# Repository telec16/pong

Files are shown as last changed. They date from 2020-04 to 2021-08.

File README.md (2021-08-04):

# Analog pong

The pong game, all in analog and on your scope !

# Design explanation

TODO... The KiCAD files are well documented though.

# Build

## Score counter

I decided to build the score counter in free-form, since it has all these diodes, it would be huge on a regular PCB.

Score board top The top view seems ok...

Score board side Look at all these diodes!

Score board bottom The bottom is a little hacky, but good enough

Score board DAC Adding the DAC

Score board ramp The two produced stairs ramps
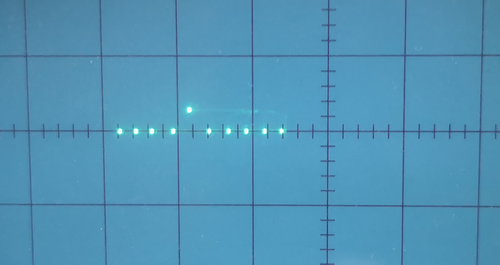
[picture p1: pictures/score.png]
Score board result It's working well!


## Goal detector

The goal detector PCB is a tilable design: you need two PCBs to make one. It lowers PCB cost (divide by two) and uses a little less components.

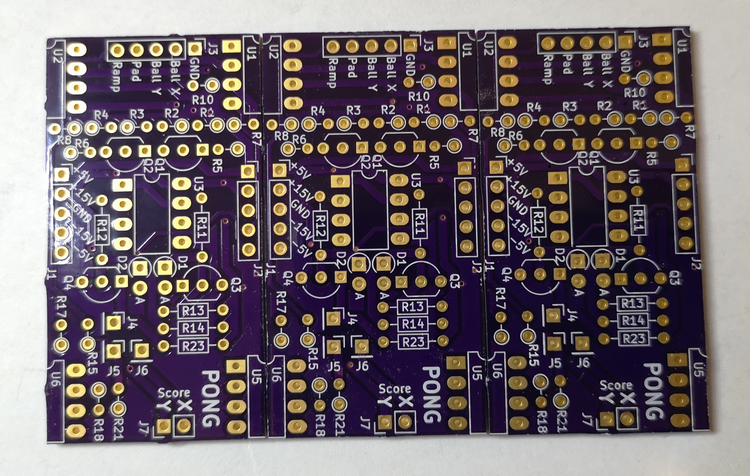
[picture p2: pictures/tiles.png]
Tiles Three PCB aligned, to make a bigger one


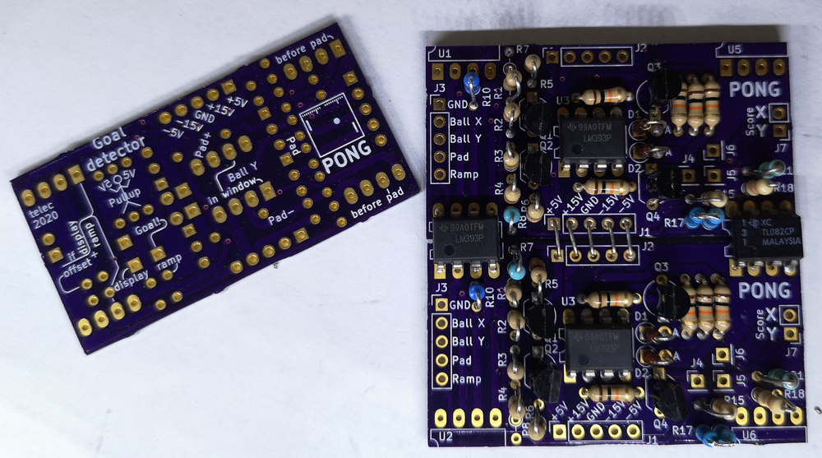
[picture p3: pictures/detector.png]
Goal detector board With all the components mounted and soldered, it works like a charm!


More pictures to come, I guess.

## Oscillator

I have hand-drawn the oscillator board, and etched it at home. It looks nice, I think.

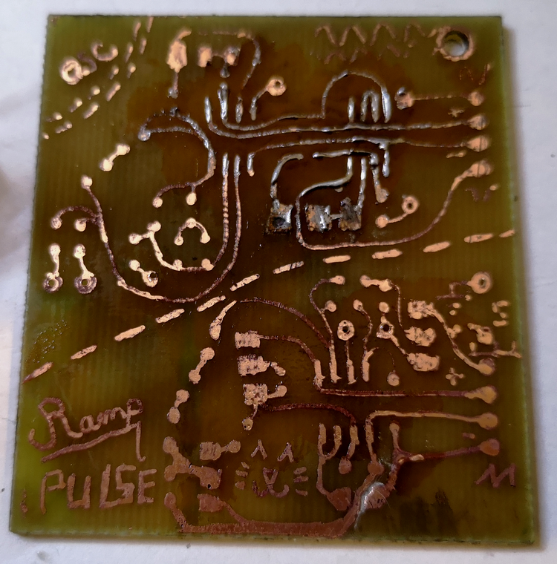
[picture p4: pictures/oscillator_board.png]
Oscillator board It's a little too much etched.


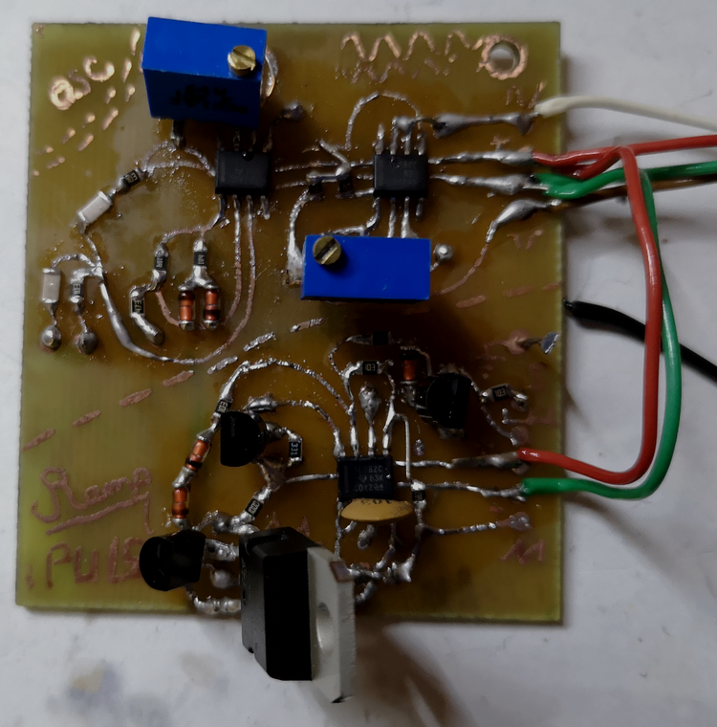
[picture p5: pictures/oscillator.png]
Oscillator board I remplaced the 2N2222 with a TIP120


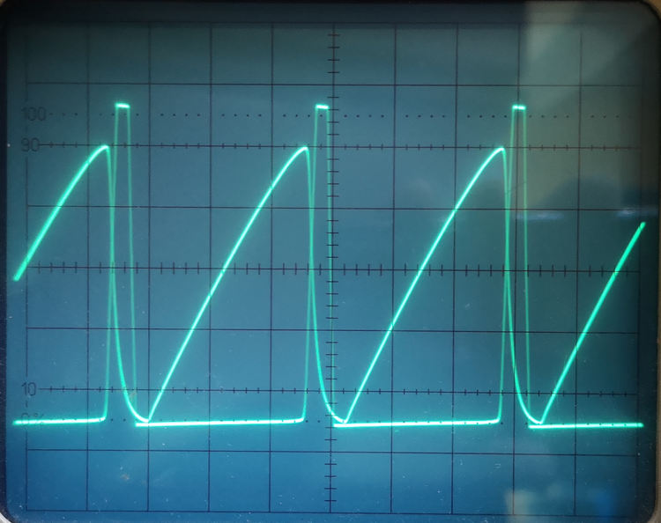
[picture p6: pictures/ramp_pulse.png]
Ramp and Pulse It works well!


The ball oscillator+phaser works well (pictures in coming). But the ramp/pulse oscillator have to put 1W in a transistor, oops... Bad design, I need to change that...

# License

This work is licensed under a [Creative Commons Attribution-ShareAlike 4.0
International License][cc-by-sa].

[][cc-by-sa]

[cc-by-sa]: http://creativecommons.org/licenses/by-sa/4.0/
[cc-by-sa-image]: https://licensebuttons.net/l/by-sa/4.0/88x31.png
[cc-by-sa-shield]: https://img.shields.io/badge/License-CC%20BY--SA%204.0-lightgrey.svg

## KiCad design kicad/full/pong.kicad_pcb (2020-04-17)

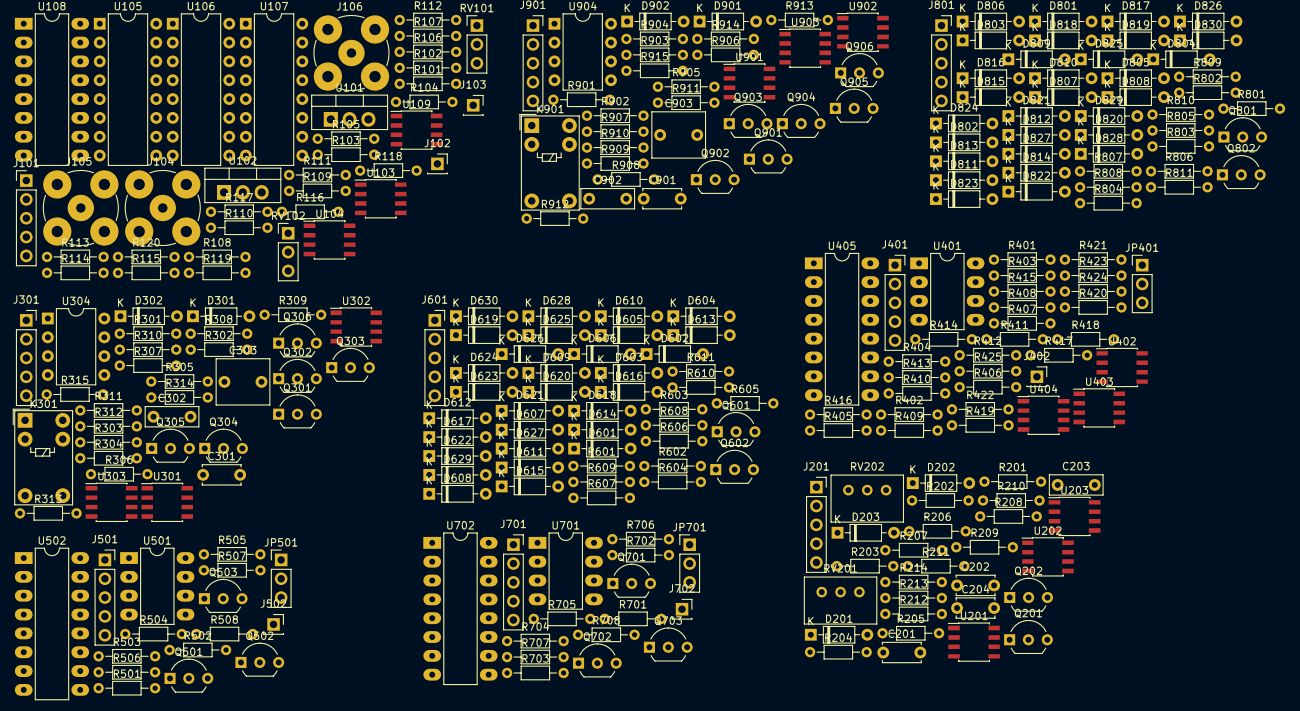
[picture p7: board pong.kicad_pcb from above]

Board: 2 copper layers, 283 parts (0 on the bottom side), 181 nets, no tracks yet.

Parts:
C201, C202, C204: 1n; C_Disc_D5.0mm_W2.5mm_P5.00mm
C203, C302, C902: 100n; C_Rect_L7.0mm_W2.5mm_P5.00mm
C301, C901: 47n; C_Disc_D5.0mm_W2.5mm_P5.00mm
C303, C903: C; C_Rect_L7.0mm_W6.0mm_P5.00mm
D201, D202, D203, D301, D302, D601, D602, D603, D604, D605, D606, D607, D608, D609, D610, D611, D612, D613, D614, D615, D616, D617, D618, D619, D620, D621, D622, D623, D624, D625, D626, D627, D628, D629, D630, D801, D802, D803, D804, D805, D806, D807, D808, D809, D810, D811, D812, D813, D814, D815, D816, D817, D818, D819, D820, D821, D822, D823, D824, D825, D826, D827, D828, D829, D830, D901, D902: 1N4148; D_DO-35_SOD27_P7.62mm_Horizontal
J101: power; PinHeader_1x05_P2.54mm_Vertical
J102: Y_F; PinSocket_1x01_P2.54mm_Vertical
J103: X_F; PinSocket_1x01_P2.54mm_Vertical
J104: X; BNC_TEConnectivity_1478204_Vertical
J105: Y; BNC_TEConnectivity_1478204_Vertical
J106: Z; BNC_TEConnectivity_1478204_Vertical
J201, J301, J401, J501, J601, J701, J801, J901: power; PinSocket_1x05_P2.54mm_Vertical
J402, J502, J702: Reset; PinSocket_1x01_P2.54mm_Vertical
JP401, JP501, JP701: Max_Point; PinHeader_1x03_P2.54mm_Vertical
K301, K901: G5V-1; Relay_SPDT_Omron_G5V-1
Q201, Q303, Q903: BC557; TO-92_Inline_Wide
Q202, Q304, Q306, Q904, Q906: 2N3819; TO-92_Inline_Wide
Q301, Q302, Q305, Q501, Q502, Q503, Q601, Q602, Q701, Q702, Q703, Q801, Q802, Q901, Q902, Q905: BC547; TO-92_Inline_Wide
R101, R102, R103, R104, R105, R106, R107, R108, R213, R310, R311, R312, R401, R402, R403, R404, R407, R408, R411, R412, R413, R414, R910, R911, R912: R; R_Axial_DIN0204_L3.6mm_D1.6mm_P7.62mm_Horizontal
R109, R112, R409, R410, R507, R707: 1k; R_Axial_DIN0204_L3.6mm_D1.6mm_P7.62mm_Horizontal
R110, R111, R405, R406: 100; R_Axial_DIN0204_L3.6mm_D1.6mm_P7.62mm_Horizontal
R113, R114, R115, R116, R117, R118, R119, R120, R205, R305, R306, R307, R905, R906, R907: 100k; R_Axial_DIN0204_L3.6mm_D1.6mm_P7.62mm_Horizontal
R201, R202, R206, R208, R210, R211, R212, R301, R302, R303, R304, R308, R309, R313, R314, R315, R416, R417, R502, R504, R505, R506, R508, R601, R602, R603, R604, R605, R606, R607, R608, R609, R610, R611, R702, R704, R705, R706, R708, R801, R802, R803, R804, R805, R806, R807, R808, R809, R810, R811, R901, R902, R903, R904, R908, R909, R913, R914, R915: 10k; R_Axial_DIN0204_L3.6mm_D1.6mm_P7.62mm_Horizontal
R203, R415: 47k; R_Axial_DIN0204_L3.6mm_D1.6mm_P7.62mm_Horizontal
R204, R207: 180k; R_Axial_DIN0204_L3.6mm_D1.6mm_P7.62mm_Horizontal
R209, R214, R501, R503, R701, R703: 4k7; R_Axial_DIN0204_L3.6mm_D1.6mm_P7.62mm_Horizontal
R418, R419, R421, R423: 33k; R_Axial_DIN0204_L3.6mm_D1.6mm_P7.62mm_Horizontal
R420, R422: 75k; R_Axial_DIN0204_L3.6mm_D1.6mm_P7.62mm_Horizontal
R424, R425: 68k; R_Axial_DIN0204_L3.6mm_D1.6mm_P7.62mm_Horizontal
RV101, RV102: R_POT; PinHeader_1x03_P2.54mm_Vertical
RV201, RV202: 10k; Potentiometer_Bourns_3299W_Vertical
U101: L7805; TO-220-3_Vertical
U102: L7905; TO-220-3_Vertical
U103, U104, U109, U201, U202, U203, U301, U302, U303, U402, U403, U404, U901, U902, U903: TL082; SOIC-8_3.9x4.9mm_P1.27mm
U105, U106, U107: DG445; DIP-16_W7.62mm
U108, U405, U502, U702: 4017; DIP-16_W7.62mm_LongPads
U304, U904: DG470; DIP-8_W7.62mm
U401, U501, U701: LM393; DIP-8_W7.62mm_LongPads

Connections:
+5V: J101.1, J201.1, J301.1, J401.1, J501.1, J601.1, J701.1, J801.1, J901.1, K301.2, K901.2, R103.1, R107.1, R111.1, R308.1, R405.2, R507.1, R508.1, R601.2, R602.2, R603.2, R604.2, R605.2, R606.2, R607.2, R608.2, R609.2, R610.2, R611.1, R707.1, R708.1, R801.2, R802.2, R803.2, R804.2, R805.2, R806.2, R807.2, R808.2, R809.2, R810.2, R811.1, R908.1, U101.3, U105.12, U106.12, U107.12, U108.16, U405.16, U502.16, U702.16
+15V: J101.2, J201.2, J301.2, J401.2, J501.2, J601.2, J701.2, J801.2, J901.2, Q202.1, Q303.3, Q903.3, R303.1, R505.1, R705.1, R903.1, U101.1, U103.4, U104.4, U105.13, U106.13, U107.13, U109.4, U201.8, U202.8, U203.8, U301.8, U302.8, U303.8, U304.4, U401.4, U402.8, U403.8, U404.8, U501.8, U701.8, U901.8, U902.8, U903.8, U904.4
-5V: J101.5, J201.5, J301.5, J401.5, J501.5, J601.5, J701.5, J801.5, J901.5, R104.2, R108.2, R110.1, R406.2, R420.2, R422.2, U102.3
-15V: C203.1, J101.4, J201.4, J301.4, J401.4, J501.4, J601.4, J701.4, J801.4, J901.4, Q201.1, R506.2, R706.2, U102.2, U103.8, U104.8, U105.4, U106.4, U107.4, U109.8, U201.4, U202.4, U203.4, U301.4, U302.4, U303.4, U304.7, U401.8, U402.4, U403.4, U404.4, U501.4, U701.4, U901.4, U902.4, U903.4, U904.7
/A: U105.1, U105.8, U108.3
/B: U106.1, U107.1, U108.2
/Ball/Bounce: R309.1, R311.1, U302.1
/Ball_X: R315.1, U105.6, U303.1
/Ball_Y: R915.1, U105.2, U903.1
/C: U106.8, U107.8, U108.4
/Cos: R913.2, RV202.1, RV202.2, U202.7
/D: U106.9, U107.9, U108.7
/Disp_Pad_1: R119.1, U106.2, U109.1
/Disp_Pad_2: R120.1, U106.6, U109.7
/E: U106.16, U107.16, U108.10
/F: U105.9, U105.16, U108.1
/New_Frame: U108.5, U108.15, U405.14
/Pad_1: R114.2, U104.1, U402.3
/Pad_2: R117.2, U104.7, U402.5
/Pos_X: C303.2, Q306.1, R312.2, R314.2, U302.7, U401.3, U401.6
/Pos_Y: C903.2, Q906.1, R912.2, R914.2, U501.3, U501.6, U701.3, U701.6, U902.7
/Pulse: J106.1, R202.1, R212.2, U108.14, U203.7
/Rampe: D201.1, R101.1, R105.1, R210.1, U203.1, U203.2
/Rampe_pad: R115.2, R118.2, U103.1
/Rampe_point: R418.2, R419.2, U103.7
/Reset: R302.1, R902.1
/Score/Q0: D602.1, D802.1, R401.1, U405.3
/Score/Q1: D604.1, D804.1, R402.1, U405.2
/Score/Q2: D606.1, D806.1, R403.1, U405.4
/Score/Q3: D608.1, D808.1, R404.1, U405.7
/Score/Q4: D610.1, D810.1, R407.1, U405.10
/Score/Q5: D612.1, D812.1, R408.1, U405.1
/Score/Q6: D614.1, D814.1, R411.1, U405.5
/Score/Q7: D616.1, D816.1, R412.1, U405.6
/Score/Q8: D618.1, D818.1, R413.1, U405.9
/Score/Q9: D620.1, D820.1, R414.1, U405.11
/Score/sheet5C9A25F6/Edge: Q503.1, R508.2, U401.7, U502.14
/Score/sheet5C9A25F6/Pad: Q501.3, Q502.1, R502.2, R503.1, U402.6, U402.7
/Score/sheet5C9A25F6/Pad+: Q501.1, R501.1, R505.2, U501.2
/Score/sheet5C9A25F6/Pad-: Q502.3, R504.2, R506.1, U501.5
/Score/sheet5C9A25F6/Score_Display: Q602.1, R419.1, R423.2
/Score/sheet5C9A25F6/sheet5C868ABE/A1: D601.1, U502.3
/Score/sheet5C9A25F6/sheet5C868ABE/B1: D603.1, U502.2
/Score/sheet5C9A25F6/sheet5C868ABE/C1: D605.1, U502.4
/Score/sheet5C9A25F6/sheet5C868ABE/D1: D607.1, U502.7
/Score/sheet5C9A25F6/sheet5C868ABE/E1: D609.1, U502.10
/Score/sheet5C9A25F6/sheet5C868ABE/F1: D611.1, U502.1
/Score/sheet5C9A25F6/sheet5C868ABE/G1: D613.1, U502.5
/Score/sheet5C9A25F6/sheet5C868ABE/H1: D615.1, U502.6
/Score/sheet5C9A25F6/sheet5C868ABE/I1: D617.1, U502.9
/Score/sheet5C9A25F6/sheet5C868ABE/J1: D619.1, U502.11
/Score/sheet5CC39077/Edge: Q703.1, R708.2, U401.1, U702.14
/Score/sheet5CC39077/Pad: Q701.3, Q702.1, R702.2, R703.1, U402.1, U402.2
/Score/sheet5CC39077/Pad+: Q701.1, R701.1, R705.2, U701.2
/Score/sheet5CC39077/Pad-: Q702.3, R704.2, R706.1, U701.5
/Score/sheet5CC39077/Score_Display: Q802.1, R418.1, R421.2
/Score/sheet5CC39077/sheet5C868ABE/A1: D801.1, U702.3
/Score/sheet5CC39077/sheet5C868ABE/B1: D803.1, U702.2
/Score/sheet5CC39077/sheet5C868ABE/C1: D805.1, U702.4
/Score/sheet5CC39077/sheet5C868ABE/D1: D807.1, U702.7
/Score/sheet5CC39077/sheet5C868ABE/E1: D809.1, U702.10
/Score/sheet5CC39077/sheet5C868ABE/F1: D811.1, U702.1
/Score/sheet5CC39077/sheet5C868ABE/G1: D813.1, U702.5
/Score/sheet5CC39077/sheet5C868ABE/H1: D815.1, U702.6
/Score/sheet5CC39077/sheet5C868ABE/I1: D817.1, U702.9
/Score/sheet5CC39077/sheet5C868ABE/J1: D819.1, U702.11
/Score_1: C301.2, Q306.2
/Score_2: C901.2, Q906.2
/Score_Display_1: R424.1, U106.10, U404.1
/Score_Display_2: R425.1, U106.15, U404.7
/Score_X: R415.1, R416.2, U107.10, U403.1
/Sin: R211.2, R313.2, RV201.1, RV201.2, U202.1
/X_out: J104.1, U105.7, U105.11, U107.3, U107.7, U107.11, U107.14
/Y_out: J105.1, U105.3, U105.14, U106.3, U106.7, U106.11, U106.14
/sheet5C7A25B3/Bounce: R909.1, R911.1, U902.1
/~Score_X: R417.1, U107.15, U403.7
GND: C201.1, C204.1, C302.1, C902.1, D301.2, D302.2, D901.2, D902.2, J101.3, J104.2, J105.2, J106.2, J201.3, J301.3, J401.3, J501.3, J601.3, J701.3, J801.3, J901.3, JP401.1, JP501.1, JP701.1, Q301.3, Q302.3, Q305.3, Q503.3, Q601.3, Q602.3, Q703.3, Q801.3, Q802.3, Q901.3, Q902.3, Q905.3, R102.2, R106.2, R109.2, R112.2, R113.2, R116.2, R201.1, R203.1, R208.1, R213.1, R301.2, R409.2, R410.2, R901.2, U101.2, U102.1, U103.3, U103.5, U104.3, U104.5, U105.5, U106.5, U107.5, U108.8, U108.13, U203.6, U301.5, U302.2, U302.5, U303.3, U304.3, U304.5, U403.3, U403.5, U404.3, U404.5, U405.8, U405.13, U502.8, U502.13, U702.8, U702.13, U901.5, U902.2, U902.5, U903.3, U904.3, U904.5
unnamed: C201.2, C202.2, R201.2, U201.3
unnamed: C202.1, R206.2
unnamed: C203.2, Q201.3, Q202.2, R205.2, U203.3
unnamed: C204.2, R211.1, U202.5
unnamed: C301.1, D301.1, Q301.2, R301.1
unnamed: C302.2, Q302.1, Q304.2, R305.2, U301.3
unnamed: C303.1, Q306.3, R310.1, U302.6
unnamed: C901.1, D901.1, Q901.2, R901.1
unnamed: C902.2, Q902.1, Q904.2, R905.2, U901.3
unnamed: C903.1, Q906.3, R910.1, U902.6
unnamed: D201.2, Q201.2, R202.2
unnamed: D202.1, D203.2, R206.1, R207.1, U201.1, U202.3
unnamed: D202.2, D203.1, R204.1
unnamed: D302.1, Q305.2, R309.2
unnamed: D601.2, D602.2, D621.2, R601.1
unnamed: D603.2, D604.2, D622.2, R602.1
unnamed: D605.2, D606.2, D623.2, R603.1
unnamed: D607.2, D608.2, D624.2, R604.1
unnamed: D609.2, D610.2, D625.2, R605.1
unnamed: D611.2, D612.2, D626.2, R606.1
unnamed: D613.2, D614.2, D627.2, R607.1
unnamed: D615.2, D616.2, D628.2, R608.1
unnamed: D617.2, D618.2, D629.2, R609.1
unnamed: D619.2, D620.2, D630.2, R610.1
unnamed: D621.1, D622.1, D623.1, D624.1, D625.1, D626.1, D627.1, D628.1, D629.1, D630.1, Q601.2
unnamed: D801.2, D802.2, D821.2, R801.1
unnamed: D803.2, D804.2, D822.2, R802.1
unnamed: D805.2, D806.2, D823.2, R803.1
unnamed: D807.2, D808.2, D824.2, R804.1
unnamed: D809.2, D810.2, D825.2, R805.1
unnamed: D811.2, D812.2, D826.2, R806.1
unnamed: D813.2, D814.2, D827.2, R807.1
unnamed: D815.2, D816.2, D828.2, R808.1
unnamed: D817.2, D818.2, D829.2, R809.1
unnamed: D819.2, D820.2, D830.2, R810.1
unnamed: D821.1, D822.1, D823.1, D824.1, D825.1, D826.1, D827.1, D828.1, D829.1, D830.1, Q801.2
unnamed: D902.1, Q905.2, R909.2
unnamed: J102.1, U105.15
unnamed: J103.1, U105.10
unnamed: J402.1, JP401.3
unnamed: J502.1, JP501.3
unnamed: J702.1, JP701.3
unnamed: JP401.2, U405.15
unnamed: JP501.2, U502.15
unnamed: JP701.2, U702.15
unnamed: K301.1, R307.1, U301.7, U304.8
unnamed: K301.5, K301.6, R310.2, U304.1
unnamed: K301.9, Q305.1, R308.2, U304.6
unnamed: K301.10, R306.1, U301.1, U301.2, U304.2
unnamed: K901.1, R907.1, U901.7, U904.8
unnamed: K901.5, K901.6, R910.2, U904.1
unnamed: K901.9, Q905.1, R908.2, U904.6
unnamed: K901.10, R906.1, U901.1, U901.2, U904.2
unnamed: Q202.3, R205.1
unnamed: Q301.1, R304.2
unnamed: Q302.2, R302.2
unnamed: Q303.1, Q304.1
unnamed: Q303.2, R303.2, R304.1
unnamed: Q304.3, R305.1
unnamed: Q501.2, R501.2, R502.1
unnamed: Q502.2, R503.2, R504.1
unnamed: Q503.2, R507.2, U501.1, U501.7
unnamed: Q601.1, Q602.2, R611.2
unnamed: Q701.2, R701.2, R702.1
unnamed: Q702.2, R703.2, R704.1
unnamed: Q703.2, R707.2, U701.1, U701.7
unnamed: Q801.1, Q802.2, R811.2
unnamed: Q901.1, R904.2
unnamed: Q902.2, R902.2
unnamed: Q903.1, Q904.1
unnamed: Q903.2, R903.2, R904.1
unnamed: Q904.3, R905.1
unnamed: R101.2, R102.1, U103.2
unnamed: R103.2, RV101.1
unnamed: R104.1, RV101.3
unnamed: R105.2, R106.1, U103.6
unnamed: R107.2, RV102.1
unnamed: R108.1, RV102.3
unnamed: R109.1, R110.2, U107.6
unnamed: R111.2, R112.1, U107.2
unnamed: R113.1, R119.2, U109.2
unnamed: R114.1, R115.1, U109.3
unnamed: R116.1, R120.2, U109.6
unnamed: R117.1, R118.1, U109.5
unnamed: R203.2, R204.2, R207.2, U201.2
unnamed: R208.2, R209.2, U202.2
unnamed: R209.1, RV201.3
unnamed: R210.2, R212.1, U203.5
unnamed: R213.2, R214.2, U202.6
unnamed: R214.1, RV202.3
unnamed: R306.2, R307.2, U301.6
unnamed: R311.2, R312.1, U302.3
unnamed: R313.1, R314.1, R315.2, U303.2
unnamed: R401.2, R402.2, R403.2, R404.2, R407.2, R408.2, R411.2, R412.2, R413.2, R414.2, R415.2, U403.2
unnamed: R405.1, R409.1, U401.2
unnamed: R406.1, R410.1, U401.5
unnamed: R416.1, R417.2, U403.6
unnamed: R420.1, R421.1, R424.2, U404.2
unnamed: R422.1, R423.1, R425.2, U404.6
unnamed: R906.2, R907.2, U901.6
unnamed: R911.2, R912.1, U902.3
unnamed: R913.1, R914.1, R915.2, U903.2
unnamed: RV101.2, U104.2
unnamed: RV102.2, U104.6

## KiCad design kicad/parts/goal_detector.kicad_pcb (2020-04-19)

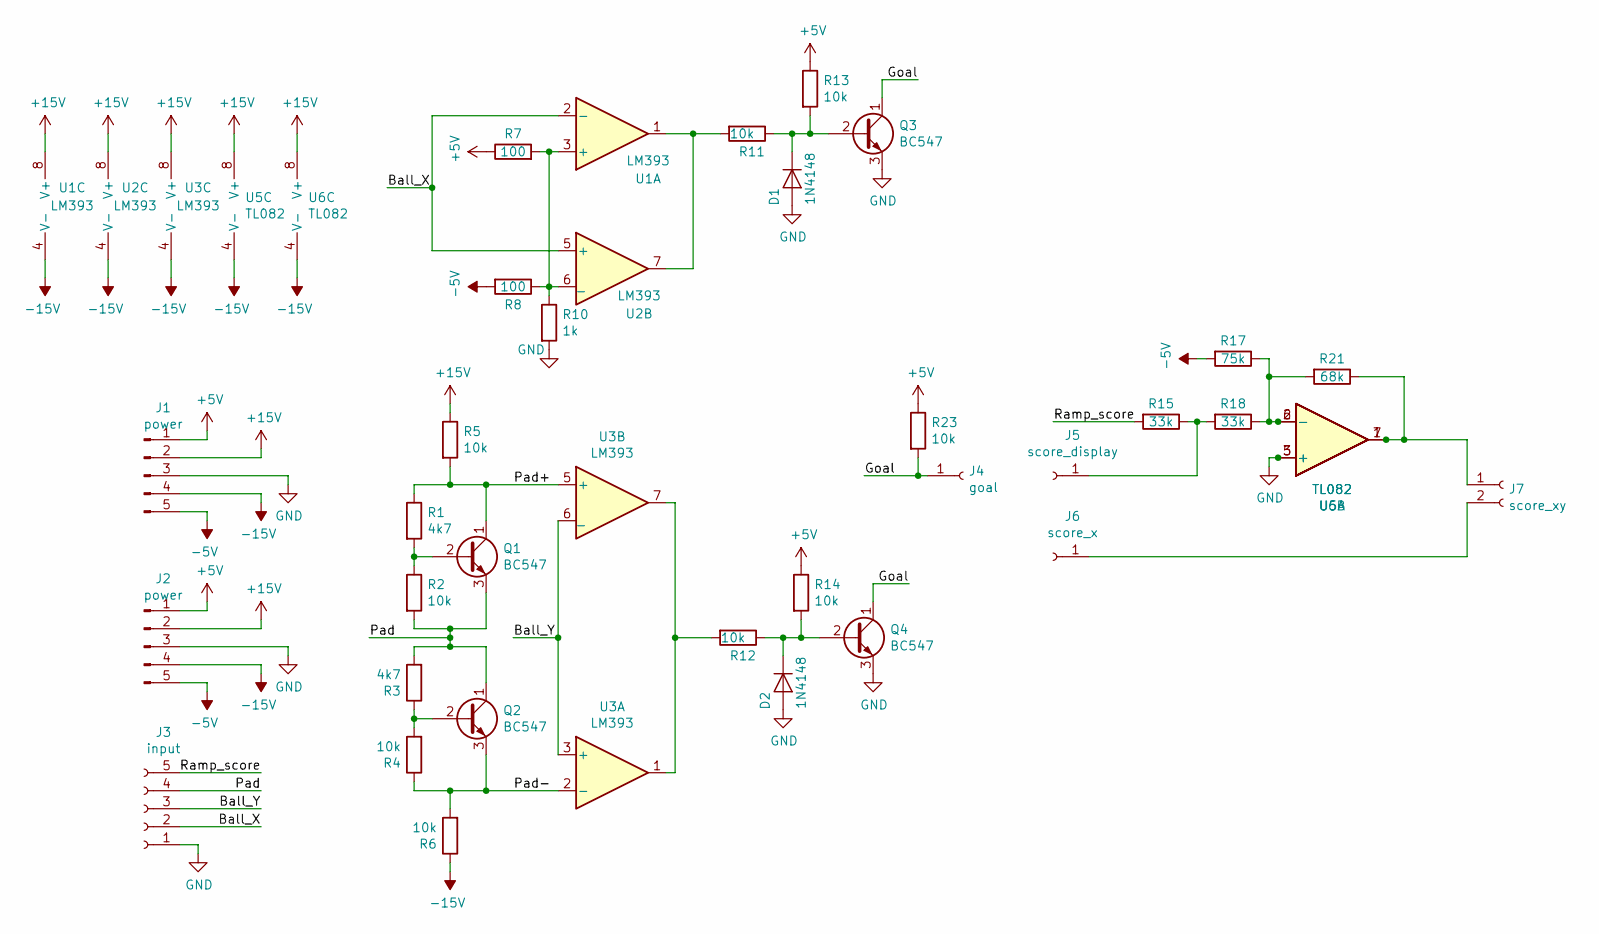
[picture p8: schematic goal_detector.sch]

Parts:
D1, D2: 1N4148; D_A-405_P2.54mm_Vertical_AnodeUp
J1, J2: power; PinSocket_1x05_P2.54mm_Vertical
J3: input; PinHeader_1x05_P2.54mm_Vertical
J4: goal; PinHeader_1x01_P2.54mm_Vertical
J5: score_display; PinHeader_1x01_P2.54mm_Vertical
J6: score_x; PinHeader_1x01_P2.54mm_Vertical
J7: score_xy; PinHeader_1x02_P2.54mm_Vertical
Q1, Q2, Q3, Q4: BC547; TO-92_Inline_Wide
R1, R3: 4k7; R_Axial_DIN0204_L3.6mm_D1.6mm_P2.54mm_Vertical
R2, R4, R5, R6: 10k; R_Axial_DIN0204_L3.6mm_D1.6mm_P2.54mm_Vertical
R7, R8: 100; R_Axial_DIN0204_L3.6mm_D1.6mm_P2.54mm_Vertical
R10: 1k; R_Axial_DIN0204_L3.6mm_D1.6mm_P2.54mm_Vertical
R11, R12, R13, R14, R23: 10k; R_Axial_DIN0204_L3.6mm_D1.6mm_P7.62mm_Horizontal
R15, R18: 33k; R_Axial_DIN0204_L3.6mm_D1.6mm_P2.54mm_Vertical
R17: 75k; R_Axial_DIN0204_L3.6mm_D1.6mm_P2.54mm_Vertical
R21: 68k; R_Axial_DIN0204_L3.6mm_D1.6mm_P2.54mm_Vertical
U1, U2, U3: LM393; DIP-8_W7.62mm_LongPads
U5, U6: TL082; DIP-8_W7.62mm_LongPads

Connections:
+5V: J1.1, J2.1, R7.1, R13.1, R14.1, R23.1
+15V: J1.2, J2.2, R5.1, U1.8 (V+), U2.8 (V+), U3.8 (V+), U5.8 (V+), U6.8 (V+)
-5V: J1.5, J2.5, R8.2, R17.2
-15V: J1.4, J2.4, R6.1, U1.4 (V-), U2.4 (V-), U3.4 (V-), U5.4 (V-), U6.4 (V-)
/Ball_X: J3.2, U1.2 (-), U2.5 (+)
/Ball_Y: J3.3, U3.3 (+), U3.6 (_)
/Goal: J4.1, Q3.1 (C), Q4.1 (C), R23.2
/Pad: J3.4, Q1.3 (E), Q2.1 (C), R2.2, R3.2
/Pad+: Q1.1 (C), R1.1, R5.2, U3.5 (+)
/Pad-: Q2.3 (E), R4.1, R6.2, U3.2 (-)
/Ramp_score: J3.5, R15.2
GND: D1.2 (A), D2.2 (A), J1.3, J2.3, J3.1, Q3.3 (E), Q4.3 (E), R10.2, U5.3 (+), U6.5 (+)
unnamed: D1.1 (K), Q3.2 (B), R11.1, R13.2
unnamed: D2.1 (K), Q4.2 (B), R12.1, R14.2
unnamed: J5.1, R15.1, R18.2
unnamed: J6.1, J7.2
unnamed: J7.1, R21.1, U5.1, U6.7
unnamed: Q1.2 (B), R1.2, R2.1
unnamed: Q2.2 (B), R3.1, R4.2
unnamed: R7.2, R8.1, R10.1, U1.3 (+), U2.6 (_)
unnamed: R11.2, U1.1, U2.7
unnamed: R12.2, U3.1, U3.7
unnamed: R17.1, R18.1, R21.2, U5.2 (-), U6.6 (-)

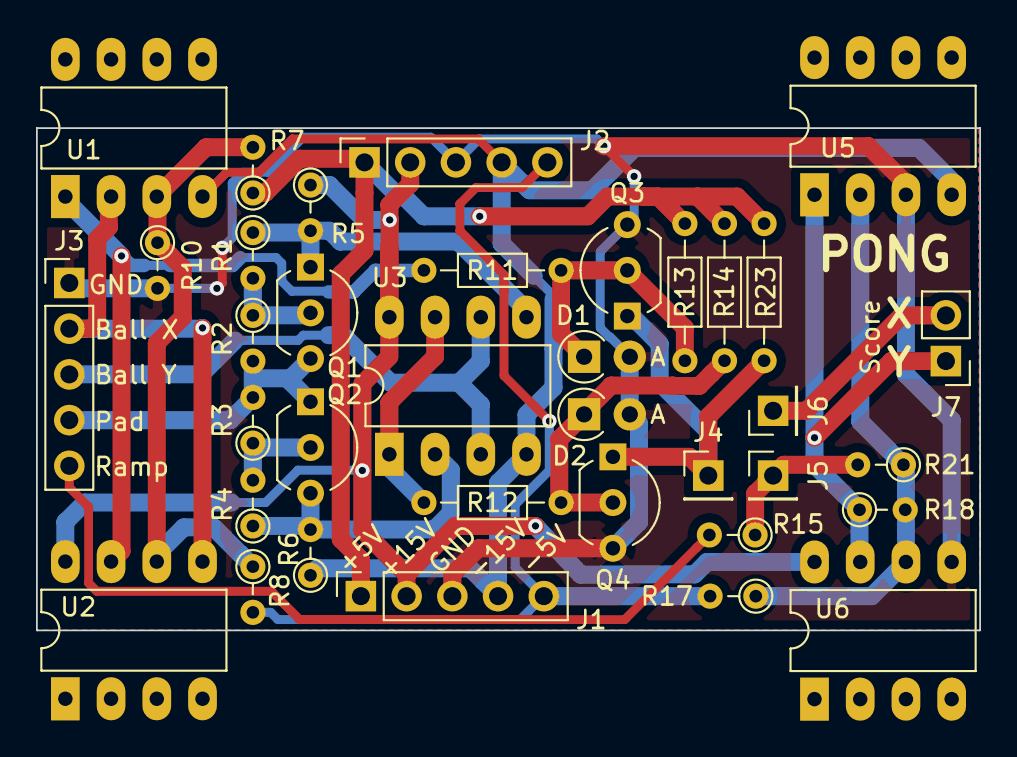
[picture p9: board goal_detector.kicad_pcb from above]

Board: 2 copper layers, 52.4 x 27.9 mm, 36 parts (0 on the bottom side), 23 nets.

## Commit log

2020-04-17 Completed schematic, needs check
    [AND_OR.sch, Ball.sch, Score.sch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]
2020-04-17 Tested oscillators
    [osc.sch]
2020-04-17 Quick fix and documentation
    [Ball.sch, Score.sch, osc.sch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]
2020-04-18 tests and doc ok
    still need some scoring options
    [AND_OR.sch, Ball.sch, Score.sch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]
2020-04-19 Calculated DAC's resistors
    [Score.sch]
2020-04-19 Small fixes and more documentation
    [Score.sch, Score_Counter.sch]
2020-04-19 Started creating the PCBs
    [AND_OR.sch, Ball.sch, Score.sch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]
2020-04-20 Changed some parts to sourcable ones
    [AND_OR.sch, Ball.sch, Score_Counter.sch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]
2020-06-13 Tested goal_detector, small fix
    [AND_OR.sch, Ball.sch, Score.sch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]
2020-06-14 Tested oscillator
    [osc.sch]
2020-06-15 better ramp circuit, to be tested
2020-06-22 new ramp design
    [osc.sch]
2021-08-04 Small correction
    [osc.sch]
